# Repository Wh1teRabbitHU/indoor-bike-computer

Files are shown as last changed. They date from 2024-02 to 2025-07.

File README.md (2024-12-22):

# indoor-bike-computer

- [indoor-bike-computer](#indoor-bike-computer)
	- [Description](#description)
	- [Sensors](#sensors)
		- [Candelance sensor](#candelance-sensor)
		- [Difficulty sensor](#difficulty-sensor)
	- [Firmware](#firmware)
	- [Images](#images)
		- [Computer 3D render, Front](#computer-3d-render-front)
		- [Computer 3D render, Back](#computer-3d-render-back)

## Description

It's a custom computer for indoor bikes to measure cadence, speed and power, store sessions, visualise ongoing statistics and replace non chargeable solutions. This project is created for the [Joroto X2 Pro](https://jorotofitness.com/products/joroto-x2pro-bluetooth-stationary-exercise-bike) indoor bike, but can be used with any other, similarly operating bikes as well!

The sensors connect to the unit the following way:

There are 2 sensor headers on the computer, one for the Candelance sensor and the other to measure the manual difficulty adjustment knob.

## Sensors

### Candelance sensor

You need to connect the following 2 pins:

- Revolution signal: This signal sends a pulse whenever the bike's crank is aligned with the sensor. The signal is triggered once every revolution and the speed is calculated based on the time difference between two pulse. For precise distance measurement, you can change the default values of the bike in the settings.
- GND: This is the shared GND line

### Difficulty sensor

You need to connect the following 3 pins:

- +3V3: This powers the sensor on the bike
- Difficulty signal: This comes from the knob, and depending on the current difficulty level, it provides a voltage between GND and +3V3 volt. (it's not a linear value and there is a starting and ending voltage level) This can be calibrated in the settings on the computer for a precise measurement.
- GND: This is the shared GND line

## Firmware

I'm using [LVGL](https://lvgl.io/) an open source embedded graphics library, to handle the UI elements for the computer. The drivers for the various chips and the bike are custom made and can be located under the `Firmware/STM32F446/Core/Inc/Drivers` and `Firmware/STM32F446/Core/Src/Drivers` folders.

List of drivers:

- ER_TFT035: Display driver. [Details](https://www.buydisplay.com/serial-spi-3-5-inch-tft-lcd-module-in-320x480-optl-touchscreen-ili9488)
- MCP3421: ADC chip from MicroChip. [Details](https://www.microchip.com/en-us/product/mcp3421)
- SD card: SD card middleware on top of the FatFS implementation, to make handling file read and write simpler

## Images

### Computer 3D render, Front
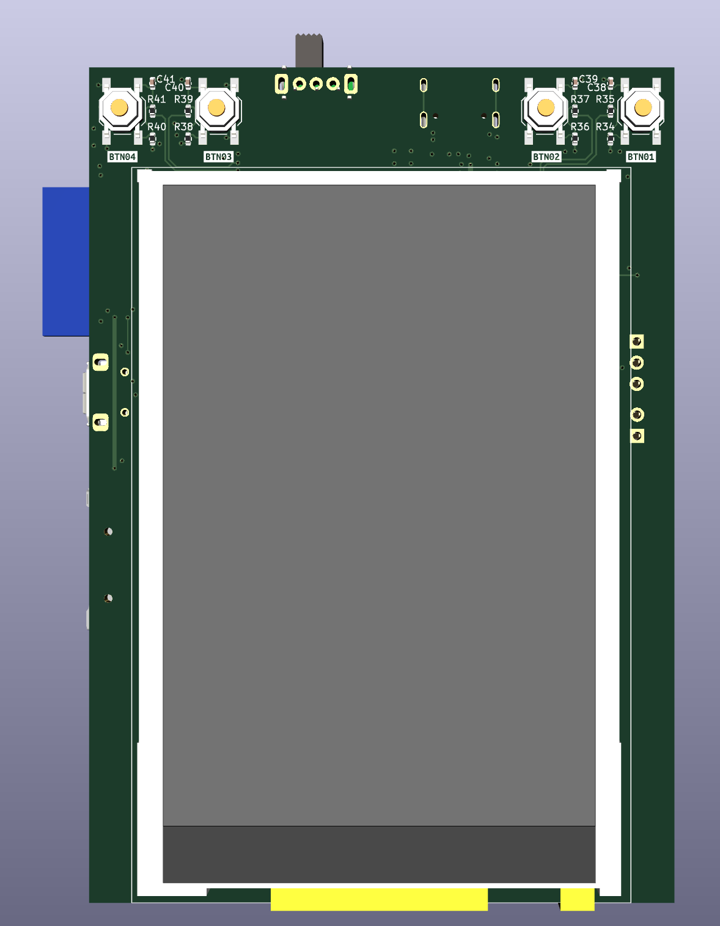
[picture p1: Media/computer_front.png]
Computer 3D - Front


### Computer 3D render, Back
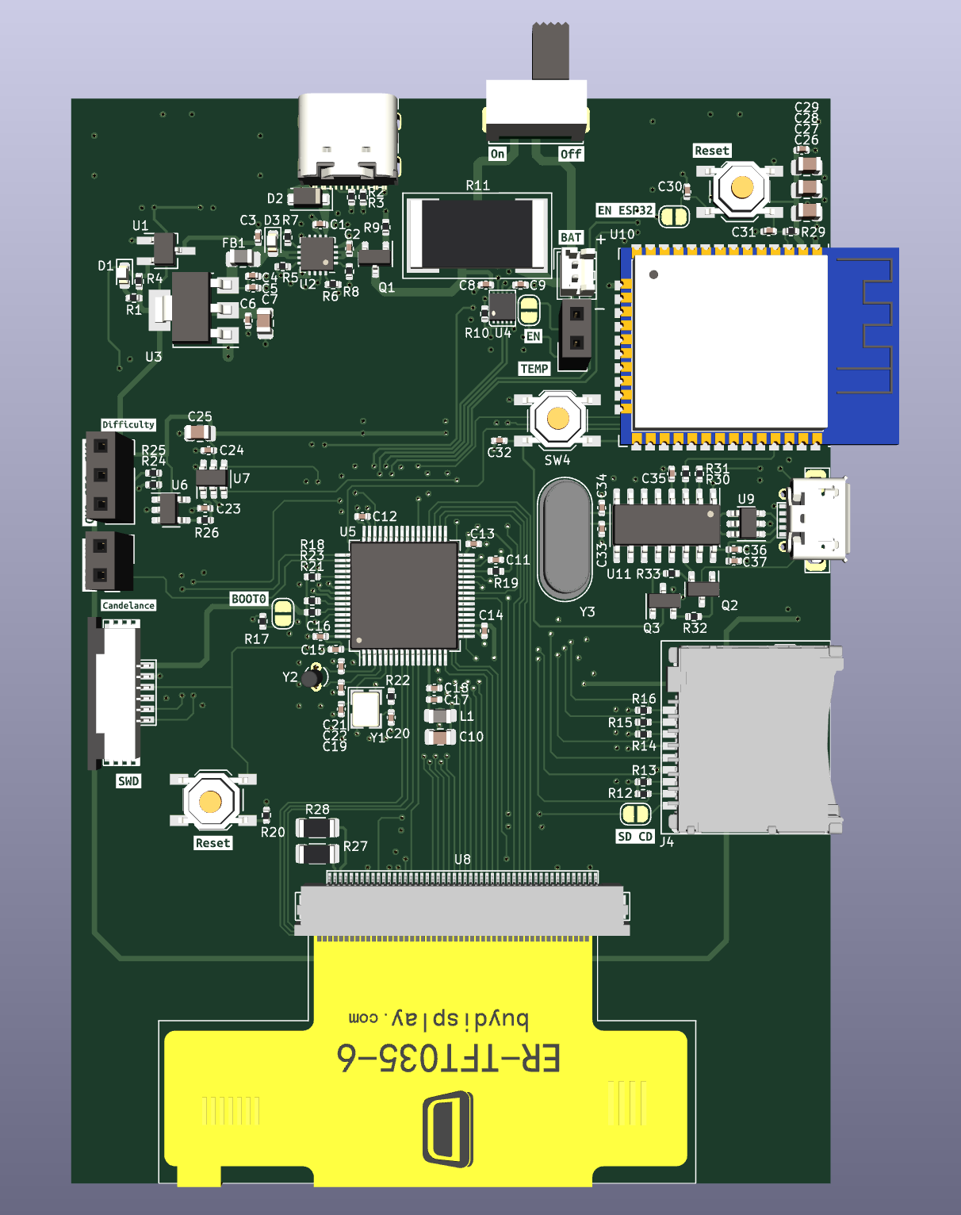
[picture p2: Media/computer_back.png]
Computer 3D - Back


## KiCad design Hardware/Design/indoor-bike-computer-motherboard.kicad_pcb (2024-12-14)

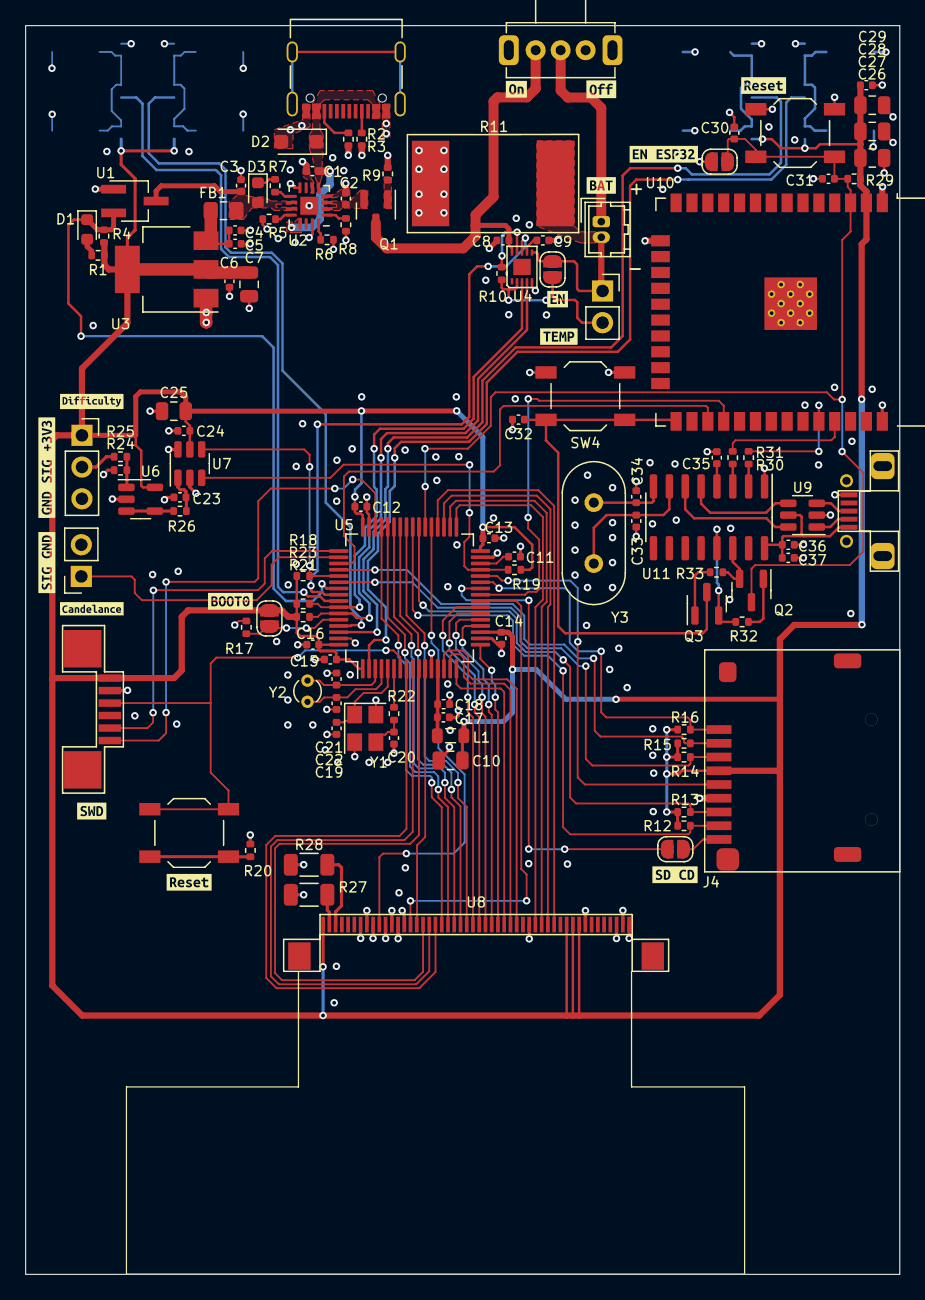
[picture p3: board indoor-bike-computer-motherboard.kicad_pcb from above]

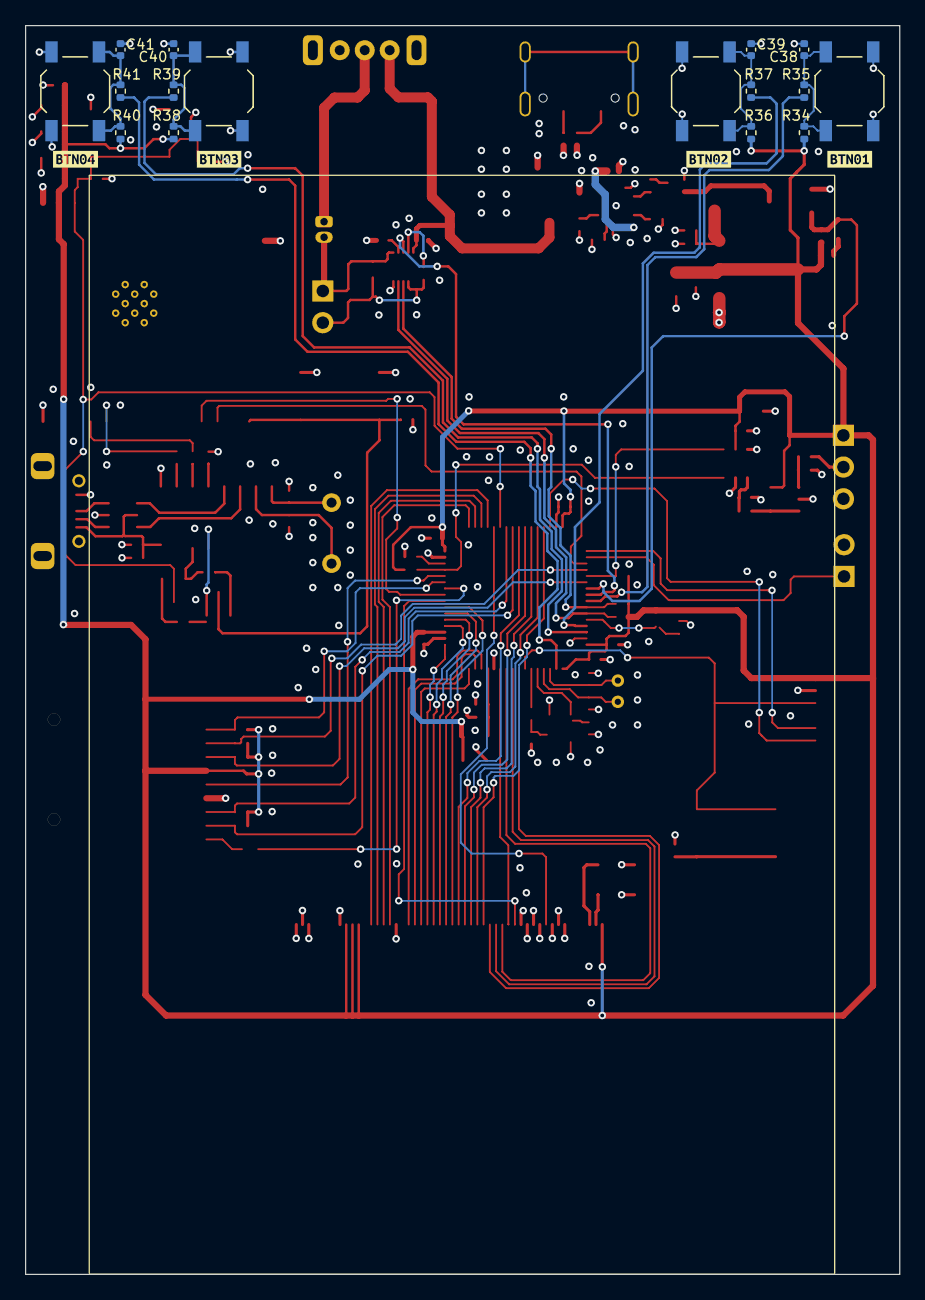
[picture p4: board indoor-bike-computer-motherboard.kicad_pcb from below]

Board: 4 copper layers, 70.0 x 100.0 mm, 143 parts (20 on the bottom side), 105 nets.

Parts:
C1, C9, C17, C23: 1uF; C_0402_1005Metric
C2, C3, C4, C11, C36: 4.7uF; C_0402_1005Metric
C5, C6, C8, C12, C13, C14, C15, C16, C18, C24, C29, C30, C31, C32, C35, C37, C38, C39, C40, C41: 0.1uF; C_0402_1005Metric
C7, C10, C25: 10uF; C_0805_2012Metric
C19, C20: 26pF; C_0402_1005Metric
C21, C22: 12pF; C_0402_1005Metric
C26, C27, C28: 22uF; C_0805_2012Metric
C33, C34: 15pF; C_0402_1005Metric
D1: Power Alert; LED_0603_1608Metric
D2: SMF6.0A; D_SOD-123F
D3: Charging; LED_0603_1608Metric
FB1: FerriteBead_Small; L_0805_2012Metric_Pad1.15x1.40mm_HandSolder
J1: USB_C_Receptacle_PowerOnly_6P; USB_C_Receptacle U262-161N-4BVC11
J2: Battery Terminal; Hirose_DF13-02P-1.25DSA_1x02_P1.25mm_Vertical
J3: THRM Socket; PinSocket_1x02_P2.54mm_Vertical
J4: Micro_SD_Card; MicroSD-TF-015
J5: SWD; AFA07-S06FCA-00
J6: Difficulty Header; PinSocket_1x03_P2.54mm_Vertical
J7: Candelance Header; PinSocket_1x02_P2.54mm_Vertical
J8: ESP32 Programmer; Micro_USB_B_Female
JP1: AIN_JMP; SolderJumper-2_P1.3mm_Open_RoundedPad1.0x1.5mm
JP2: SD_CD JP; SolderJumper-2_P1.3mm_Open_RoundedPad1.0x1.5mm
JP3: Jumper_2_Open; SolderJumper-2_P1.3mm_Open_RoundedPad1.0x1.5mm
JP4: EN_ESP32; SolderJumper-2_P1.3mm_Open_RoundedPad1.0x1.5mm
L1: 39nH; L_0805_2012Metric
Q1: AO3401A; SOT-23
Q2, Q3: BC849; SOT-23
R1: 1.5k; R_0402_1005Metric
R2, R3: 5.1kΩ; R_0402_1005Metric
R4: 100k; R_0402_1005Metric
R5: 1K1Ω; R_0402_1005Metric
R6: 590Ω; R_0402_1005Metric
R7, R35, R37, R39, R41: 1K; R_0402_1005Metric
R8, R9, R34, R36, R38, R40: 10K; R_0402_1005Metric
R10, R12, R13, R14, R15, R16, R17, R20, R24, R25, R29, R32, R33: 10k; R_0402_1005Metric
R11: 10mΩ; Resistor_SMD_4527
R18, R19, R21, R23: 2k2; R_0402_1005Metric
R22, R30, R31: 100; R_0402_1005Metric
R26: 220; R_0402_1005Metric
R27, R28: 10Ω; R_1206_3216Metric
SW1: Enable; Toggle-Switch-SK12D07VG4
SW2: Reset Button; SW_SPST_TL3342
SW3: Reset BTN; SW_SPST_TL3342
SW4: Flash BTN; SW_SPST_TL3342
SW5, SW6, SW7, SW8: Button_01; SW_SPST_TL3342
U1: APX803L05-36SA-7; SOT-23W_Handsoldering
U2: BQ24078RGTR; VQFN-16-1EP_3x3mm_P0.5mm_EP1.45x1.45mm
U3: LDL1117S33R; SOT-223-3_TabPin2
U4: MAX17055ETB+T; TDFN-EP-10-2.0x2.5
U5: STM32F446RETx; LQFP-64_10x10mm_P0.5mm
U6: LMV321; SOT-23-5
U7: MCP3421A0T-ECH; SOT-23-6
U8: ER-TFT035-6
U9: USBLC6-2SC6; SOT-23-6
U10: ESP32-WROOM-32
U11: CH340G; SOIC-16_3.9x9.9mm_P1.27mm
Y1: 8MHz; Crystal_SMD_Abracon_ABM8G-4Pin_3.2x2.5mm
Y2: 32768Hz; Crystal_Round_D1.5mm_Vertical
Y3: 12MHz; Crystal_HC49-4H_Vertical
kibuzzard-66A143C0: G***; kibuzzard-66A143C0
kibuzzard-66A143CA: G***; kibuzzard-66A143CA
kibuzzard-66A145A5: G***; kibuzzard-66A145A5
kibuzzard-66A145C4: G***; kibuzzard-66A145C4
kibuzzard-66A145EF: G***; kibuzzard-66A145EF
kibuzzard-66A146E2: G***; kibuzzard-66A146E2
kibuzzard-66A1432C: G***; kibuzzard-66A1432C
kibuzzard-66A1459C: G***; kibuzzard-66A1459C
kibuzzard-66A1487C: G***; kibuzzard-66A1487C
kibuzzard-66A1489C: G***; kibuzzard-66A1489C
kibuzzard-66A14353: G***; kibuzzard-66A14353
kibuzzard-66A14385: G***; kibuzzard-66A14385
kibuzzard-66A14397: G***; kibuzzard-66A14397
kibuzzard-66A14462: G***; kibuzzard-66A14462
kibuzzard-66A14469: G***; kibuzzard-66A14469
kibuzzard-66A14601: G***; kibuzzard-66A14601
kibuzzard-66A14776: G***; kibuzzard-66A14776
kibuzzard-66A14875: G***; kibuzzard-66A14875
kibuzzard-66A14886: G***; kibuzzard-66A14886

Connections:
+3.3VA: C17.1, C18.1, L1.1, U5.13 (VDDA)
/ESP32_MCU/+3V3: C6.1, C7.1, C10.1, C12.1, C13.1, C14.1, C15.1, C16.1, C24.2, C25.1, C26.1, C27.1, C28.1, C29.1, J4.4 (VDD), J5.1, J6.1, JP3.2 (B), L1.2, R1.1, R4.1, R12.2, R13.2, R14.2, R15.2, R16.2, R18.1, R19.1, R21.1, R23.1, R29.2, R34.1, R36.1, R38.1, R40.1, U3.2 (OUT), U5.1 (VBAT), U5.19 (VDD), U5.32 (VDD), U5.48 (VDD), U5.64 (VDD), U6.5 (V+), U7.5 (Vdd), U8.1 (LEDA), U8.40 (VDDI), U8.41 (VDDI), U8.42 (VCI), U10.2 (VDD)
/ESP32_MCU/ESP32_5V: C36.1, C37.1, J8.1 (VBUS), U9.5 (VBUS), U11.16 (VCC)
/ESP32_MCU/GND: C1.2, C2.2, C3.2, C4.2, C5.2, C6.2, C7.2, C8.2, C9.2, C10.2, C11.2, C12.2, C13.2, C14.2, C15.2, C16.2, C17.2, C18.2, C19.1, C20.2, C21.2, C22.2, C23.2, C24.1, C25.2, C26.2, C27.2, C28.2, C29.2, C30.2, C31.2, C32.2, C33.2, C34.2, C35.2, C36.2, C37.2, C38.2, C39.2, C40.2, C41.2, D2.2 (A2), J1.A1, J1.A12 (GND), J1.B1, J1.B12 (GND), J4.6 (VSS), J5.2, J6.3, J7.2, J8.5 (GND), JP4.1 (A), R2.2, R3.2, R5.1, R6.1, R8.2, R9.2, R11.2, R17.2, R20.2, R25.1, R27.2, R28.2, SW3.2, SW4.2, SW5.1, SW6.1, SW7.1, SW8.1, U1.1 (GND), U2.4 (!CE), U2.6 (EN1), U2.8 (VSS), U2.15 (SYSOFF), U2.17 (PAD), U3.1 (GND), U4.5 (CSN), U5.12 (VSSA), U5.18 (VSS), U5.31 (VSS), U5.47 (VSS), U5.63 (VSS), U6.2 (V-), U7.2 (Vss), U7.6 (Vin-), U8.7 (IM0), U8.8 (IM1), U8.9 (IM2), U8.11 (VSYNC), U8.12 (HSYNC), U8.13 (DOTCLK), U8.14 (DE), U8.34 (SDA), U8.43 (GND), U8.48 (GND), U8.49 (GND), U8.50 (GND), U9.2 (GND), U10.1 (GND), U10.15 (GND), U10.38 (GND), U10.39 (GND), U11.1 (GND), Y1.2, Y1.4
/ESP32_MCU/IO0: C32.1, Q3.3 (C), SW4.1, U10.25 (IO0)
/ESP32_MCU/RXD0: R30.1, U10.34 (RXD0/IO3)
/ESP32_MCU/TXD0: R31.1, U10.35 (TXD0/IO1)
/ESP32_MCU/USB_D+: U9.4 (I/O2), U11.5 (UD+)
/ESP32_MCU/USB_D-: U9.6 (I/O1), U11.6 (UD-)
/ESP32_MCU/USB_D_IN+: J8.3 (D+), U9.3 (I/O2)
/ESP32_MCU/USB_D_IN-: J8.2 (D-), U9.1 (I/O1)
/Power Input/BAT+: C2.1, Q1.2 (S), U2.2 (BAT), U2.3 (BAT)
/Power Input/BAT_IN+: C8.1, Q1.3 (D), SW1.3 (C), U4.10 (BATT)
/Power Input/BAT_IN-: J2.2, J3.1, JP1.1 (A), R11.1, U4.6 (CSP)
/Power Input/PWR_OUT: C3.1, D3.2 (A), FB1.1, U1.3 (VCC), U2.10 (OUT), U2.11 (OUT)
/Power Input/VBUS: C1.1, D2.1 (A1), J1.A4, J1.A9 (VBUS), J1.B4, J1.B9 (VBUS), U2.5 (EN2), U2.13 (IN)
ADC_SCL: R19.2, U5.29 (PB10), U7.3 (SCL)
ADC_SDA: R18.2, U5.53 (PC12), U7.4 (SDA)
BOOT0: JP3.1 (A), R17.1, U5.60 (BOOT0)
DIFFICULTY_SIGNAL: J6.2, R24.2
DISPLAY_CS: U5.36 (PB15), U8.38 (CSX)
DISPLAY_D00: U5.14 (PA0), U8.32 (DB00)
DISPLAY_D01: U5.15 (PA1), U8.31 (DB01)
DISPLAY_D02: U5.16 (PA2), U8.30 (DB02)
DISPLAY_D03: U5.17 (PA3), U8.29 (DB03)
DISPLAY_D04: U5.20 (PA4), U8.28 (DB04)
DISPLAY_D05: U5.21 (PA5), U8.27 (DB05)
DISPLAY_D06: U5.22 (PA6), U8.26 (DB06)
DISPLAY_D07: U5.23 (PA7), U8.25 (DB07)
DISPLAY_D08: U5.41 (PA8), U8.24 (DB08)
DISPLAY_D09: U5.42 (PA9), U8.23 (DB09)
DISPLAY_D10: U5.43 (PA10), U8.22 (DB10)
DISPLAY_D11: U5.44 (PA11), U8.21 (DB11)
DISPLAY_D12: U5.45 (PA12), U8.20 (DB12)
DISPLAY_D13: U5.8 (PC0), U8.19 (DB13)
DISPLAY_D14: U5.9 (PC1), U8.18 (DB14)
DISPLAY_D15: U5.10 (PC2), U8.17 (DB15)
DISPLAY_D16: U5.11 (PC3), U8.16 (DB16)
DISPLAY_D17: U5.24 (PC4), U8.15 (DB17)
DISPLAY_DC: U5.35 (PB14), U8.37 (D/CX)
DISPLAY_RD: U5.33 (PB12), U8.35 (RD)
DISPLAY_RESET: U5.37 (PC6), U8.10 (RESET)
DISPLAY_WR: U5.34 (PB13), U8.36 (WRX/SCL)
NRST: J5.3, SW2.1, U5.7 (NRST)
unnamed: C20.1, R22.1, Y1.3
unnamed: C38.1, R34.2, R35.1, SW5.2
unnamed: C39.1, R36.2, R37.1, SW6.2
unnamed: C40.1, R38.2, R39.1, SW7.2
unnamed: C41.1, R40.2, R41.1, SW8.2
unnamed: D1.2 (A), R1.2
unnamed: D3.1 (K), R7.1
unnamed: J1.A5 (CC1), R3.1
unnamed: J1.B5 (CC2), R2.1
unnamed: J2.1, SW1.2 (B)
unnamed: J3.2, JP1.2 (B), R10.1, U4.2 (AIN)
unnamed: J4.9 (SHIELD), JP2.2 (B)
unnamed: Q1.1 (G), R9.1
unnamed: Q2.1 (B), R32.1
unnamed: Q2.2 (E), R33.2, U11.14 (~RTS)
unnamed: Q3.1 (B), R33.1
unnamed: Q3.2 (E), R32.2, U11.13 (~DTR)
unnamed: R20.1, SW2.2
unnamed: R27.1, U8.2 (LEDK)
unnamed: R28.1, U8.3 (LEDK)
unnamed: R7.2, U2.9 (!CHG)
unnamed: R5.2, U2.12 (ILIM)
unnamed: R6.2, U2.16 (ISET)
unnamed: R8.1, U2.1 (TS)
unnamed: C4.1, C5.1, FB1.2, U3.3 (VIN)
unnamed: C9.1, U4.7 (REG)
unnamed: R10.2, U4.9 (THRM)
unnamed: C11.1, U5.30 (VCAP_1)
unnamed: R24.1, R25.2, U6.1 (+)
unnamed: R26.1, U6.3 (-), U6.4
unnamed: C23.1, R26.2, U7.1 (Vin+)
unnamed: R31.2, U11.3 (RXD)
unnamed: R30.2, U11.2 (TXD)
unnamed: C35.1, U11.4 (V3)
unnamed: C33.1, U11.7 (XI), Y3.1
unnamed: C34.1, U11.8 (XO), Y3.2
OSC_IN: C19.2, U5.5 (PH0), Y1.1
OSC_OUT: R22.2, U5.6 (PH1)
PA13: J5.6, U5.46 (PA13)
PA14: J5.5, U5.49 (PA14)
PA15: J7.1, U5.50 (PA15)
PB0: JP2.1 (A), U5.26 (PB0)
PB1: J4.1 (DAT2), R16.1, U5.27 (PB1)
PB2: J4.5 (CLK), U5.28 (PB2)
PB3: D1.1 (K), R4.2, U1.2 (!RESET), U5.55 (PB3)
PB4: U4.8 (ALERT), U5.56 (PB4)
PB5: R35.2, U5.57 (PB5)
PB6: R23.2, U4.3 (SCL), U5.58 (PB6)
PB7: R21.2, U4.4 (SDA), U5.59 (PB7)
PB8: R37.2, U5.61 (PB8)
PB9: R39.2, U5.62 (PB9)
PC5: U5.25 (PC5), U10.28 (IO17)
PC7: C30.1, C31.1, JP4.2 (B), Q2.3 (C), R29.1, SW3.1, U5.38 (PC7), U10.3 (EN)
PC8: J4.7 (DAT0), R13.1, U5.39 (PC8)
PC9: J4.8 (DAT1), R12.1, U5.40 (PC9)
PC10: U5.51 (PC10), U10.27 (IO16)
PC11: J4.2 (DAT3/CD), R15.1, U5.52 (PC11)
PC13: R41.2, U5.2 (PC13)
PC14: C21.1, U5.3 (PC14), Y2.1
PC15: C22.1, U5.4 (PC15), Y2.2
PD2: J4.3 (CMD), R14.1, U5.54 (PD2)

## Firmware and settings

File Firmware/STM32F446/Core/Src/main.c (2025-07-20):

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
/* Includes ------------------------------------------------------------------*/
#include "main.h"
#include "fatfs.h"

/* USER CODE BEGIN Includes */
#include "bike.h"
#include "config.h"
#include "data.h"
#include "er_tft035.h"
#include "esp32_uart.h"
#include "gui.h"
#include "main_screen.h"
#include "max17055.h"
#include "mcp3421.h"
#include "stdio.h"
/* USER CODE END Includes */

I2C_HandleTypeDef hi2c1;
I2C_HandleTypeDef hi2c2;

RTC_HandleTypeDef hrtc;

SD_HandleTypeDef hsd;

TIM_HandleTypeDef htim6;
TIM_HandleTypeDef htim7;
TIM_HandleTypeDef htim14;

UART_HandleTypeDef huart3;
DMA_HandleTypeDef hdma_usart3_rx;
DMA_HandleTypeDef hdma_usart3_tx;

void SystemClock_Config(void);
static void MX_GPIO_Init(void);
static void MX_DMA_Init(void);
static void MX_I2C1_Init(void);
static void MX_I2C2_Init(void);
static void MX_SDIO_SD_Init(void);
static void MX_USART3_UART_Init(void);
static void MX_RTC_Init(void);
static void MX_TIM14_Init(void);
static void MX_TIM6_Init(void);
static void MX_TIM7_Init(void);
/* USER CODE BEGIN 0 */

void SDCard_handleError(FRESULT result, char * message) {
    MainScreen_showAlert(ALERT_MODAL_VARIANT_ERROR, 1, "SD card error", message);
}

/* USER CODE END 0 */

/**
 * @brief  The application entry point.
 * @retval int
 */
int main(void) {
    /* MCU Configuration--------------------------------------------------------*/

    /* Reset of all peripherals, Initializes the Flash interface and the Systick. */
    HAL_Init();

    /* Configure the system clock */
    SystemClock_Config();

    /* Initialize all configured peripherals */
    MX_GPIO_Init();
    MX_DMA_Init();
    MX_I2C1_Init();
    MX_I2C2_Init();
    MX_SDIO_SD_Init();
    MX_USART3_UART_Init();
    MX_RTC_Init();
    MX_TIM14_Init();
    MX_FATFS_Init();
    MX_TIM6_Init();
    MX_TIM7_Init();
    /* USER CODE BEGIN 2 */

    Bike_init(&htim6);
    GUI_init();

    uint8_t sdCardOk = Data_initStorage();

    if (sdCardOk) {
        Data_loadStatistics();
        Config_load();
    } else {
        MainScreen_showAlert(ALERT_MODAL_VARIANT_ERROR, 0, "SD card error", "Unable to initialize the computer, the SD card is missing or not readable!");
    }

    HAL_StatusTypeDef adcInitResult = MCP3421_init(&hi2c2);

    if (adcInitResult == HAL_OK) {
        HAL_TIM_Base_Start_IT(&htim14); // Start timer
        HAL_TIM_Base_Start_IT(&htim7);
    } else if (sdCardOk) {
        MainScreen_showAlert(ALERT_MODAL_VARIANT_ERROR, 0, "Sensor error", "Unable to initialize the computer, one of the sensors is not responding!");
    }

    // MAX17055_init(&hi2c1);

    ESP32_initCommunication(&huart3);

    /* USER CODE END 2 */

    /* Infinite loop */
    /* USER CODE BEGIN WHILE */
    // MAX17055_measurements measurements;

    while (1) {
        /* USER CODE END WHILE */

        /* USER CODE BEGIN 3 */
        uint32_t waitTime = GUI_tick();

        HAL_Delay(waitTime);

        // MAX17055_readMeasurements(&measurements);
        // sprintf(stringBuffer, "Measurements:\n%lu, %lu,\n %lu, %lu", measurements.instantVoltage, measurements.instantCurrent, measurements.instantCapacity, measurements.temperature);
        // MainScreen_showAlert(ALERT_MODAL_VARIANT_INFO, 0, "Measurements", stringBuffer);
    }
    /* USER CODE END 3 */
}

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
/* USER CODE BEGIN 4 */

ESP32_UART_Packet packet = {0};

void HAL_UART_RxCpltCallback(UART_HandleTypeDef * huart) {
    ESP32_receiveData(&packet);

    MainScreen_showAlert(ALERT_MODAL_VARIANT_INFO, 0, "Received Data", (char *)packet.data);
}

/* USER CODE END 4 */
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


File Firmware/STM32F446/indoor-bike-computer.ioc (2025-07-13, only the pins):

Mcu.UserName=STM32F446RETx
PA0-WKUP.GPIO_Label=DISPLAY_D00
PA0-WKUP.Signal=GPIO_Output
PA1.GPIO_Label=DISPLAY_D01
PA1.Signal=GPIO_Output
PA10.GPIO_Label=DISPLAY_D10
PA10.Signal=GPIO_Output
PA11.GPIO_Label=DISPLAY_D11
PA11.Signal=GPIO_Output
PA12.GPIO_Label=DISPLAY_D12
PA12.Signal=GPIO_Output
PA13.Signal=SYS_JTMS-SWDIO
PA14.Signal=SYS_JTCK-SWCLK
PA15.GPIO_Label=REVOLUTION_SIGNAL
PA15.Signal=GPXTI15
PA2.GPIO_Label=DISPLAY_D02
PA2.Signal=GPIO_Output
PA3.GPIO_Label=DISPLAY_D03
PA3.Signal=GPIO_Output
PA4.GPIO_Label=DISPLAY_D04
PA4.Signal=GPIO_Output
PA5.GPIO_Label=DISPLAY_D05
PA5.Signal=GPIO_Output
PA6.GPIO_Label=DISPLAY_D06
PA6.Signal=GPIO_Output
PA7.GPIO_Label=DISPLAY_D07
PA7.Signal=GPIO_Output
PA8.GPIO_Label=DISPLAY_D08
PA8.Signal=GPIO_Output
PA9.GPIO_Label=DISPLAY_D09
PA9.Signal=GPIO_Output
PB0.GPIO_Label=SDIO_CD
PB0.Signal=GPIO_Input
PB10.Signal=I2C2_SCL
PB12.GPIO_Label=DISPLAY_RD
PB12.Signal=GPIO_Output
PB13.GPIO_Label=DISPLAY_WR
PB13.Signal=GPIO_Output
PB14.GPIO_Label=DISPLAY_DC
PB14.Signal=GPIO_Output
PB15.GPIO_Label=DISPLAY_CS
PB15.Signal=GPIO_Output
PB2.Signal=SDIO_CK
PB3.GPIO_Label=POWER_ALERT
PB3.Signal=GPIO_Input
PB4.GPIO_Label=GAUGE_ALERT
PB4.Signal=GPIO_Output
PB5.GPIO_Label=USER_BTN_1
PB5.Signal=GPXTI5
PB6.Signal=I2C1_SCL
PB7.Signal=I2C1_SDA
PB8.GPIO_Label=USER_BTN_2
PB8.Signal=GPXTI8
PB9.GPIO_Label=USER_BTN_3
PB9.Signal=GPXTI9
PC0.GPIO_Label=DISPLAY_D13
PC0.Signal=GPIO_Output
PC1.GPIO_Label=DISPLAY_D14
PC1.Signal=GPIO_Output
PC10.Signal=USART3_TX
PC12.Signal=I2C2_SDA
PC13.GPIO_Label=USER_BTN_4
PC13.Signal=GPXTI13
PC14-OSC32_IN.Signal=RCC_OSC32_IN
PC15-OSC32_OUT.Signal=RCC_OSC32_OUT
PC2.GPIO_Label=DISPLAY_D15
PC2.Signal=GPIO_Output
PC3.GPIO_Label=DISPLAY_D16
PC3.Signal=GPIO_Output
PC4.GPIO_Label=DISPLAY_D17
PC4.Signal=GPIO_Output
PC5.Signal=USART3_RX
PC6.GPIO_Label=DISPLAY_RESET
PC6.Signal=GPIO_Output
PC7.GPIO_Label=ESP32_EN
PC7.Signal=GPIO_Output
PC8.Signal=SDIO_D0
PD2.Signal=SDIO_CMD
PH0-OSC_IN.Signal=RCC_OSC_IN
PH1-OSC_OUT.Signal=RCC_OSC_OUT

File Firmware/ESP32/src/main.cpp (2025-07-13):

#include <Arduino.h>
#include <string.h>

void setup() {
    Serial.begin(115200);
    Serial2.begin(115200);

    delay(10);

    // We start by connecting to a WiFi network

    Serial.println();
    Serial.println();
    Serial.print("ESP32 is ready");
    Serial.println();
    Serial.println();
}

char logBuffer[128] = {'\0'};
char rxBuffer[64] = {'\0'};
char txBuffer[64] = {'\0'};
char dataBuffer[64] = {'\0'};
uint32_t counter = 0;
uint8_t bufferPointer = 0;

static const uint32_t crc32Table[256] = {
    0x00000000L, 0xF26B8303L, 0xE13B70F7L, 0x1350F3F4L, 0xC79A971FL, 0x35F1141CL, 0x26A1E7E8L, 0xD4CA64EBL, 0x8AD958CFL,
    0x78B2DBCCL, 0x6BE22838L, 0x9989AB3BL, 0x4D43CFD0L, 0xBF284CD3L, 0xAC78BF27L, 0x5E133C24L, 0x105EC76FL, 0xE235446CL,
    0xF165B798L, 0x030E349BL, 0xD7C45070L, 0x25AFD373L, 0x36FF2087L, 0xC494A384L, 0x9A879FA0L, 0x68EC1CA3L, 0x7BBCEF57L,
    0x89D76C54L, 0x5D1D08BFL, 0xAF768BBCL, 0xBC267848L, 0x4E4DFB4BL, 0x20BD8EDEL, 0xD2D60DDDL, 0xC186FE29L, 0x33ED7D2AL,
    0xE72719C1L, 0x154C9AC2L, 0x061C6936L, 0xF477EA35L, 0xAA64D611L, 0x580F5512L, 0x4B5FA6E6L, 0xB93425E5L, 0x6DFE410EL,
    0x9F95C20DL, 0x8CC531F9L, 0x7EAEB2FAL, 0x30E349B1L, 0xC288CAB2L, 0xD1D83946L, 0x23B3BA45L, 0xF779DEAEL, 0x05125DADL,
    0x1642AE59L, 0xE4292D5AL, 0xBA3A117EL, 0x4851927DL, 0x5B016189L, 0xA96AE28AL, 0x7DA08661L, 0x8FCB0562L, 0x9C9BF696L,
    0x6EF07595L, 0x417B1DBCL, 0xB3109EBFL, 0xA0406D4BL, 0x522BEE48L, 0x86E18AA3L, 0x748A09A0L, 0x67DAFA54L, 0x95B17957L,
    0xCBA24573L, 0x39C9C670L, 0x2A993584L, 0xD8F2B687L, 0x0C38D26CL, 0xFE53516FL, 0xED03A29BL, 0x1F682198L, 0x5125DAD3L,
    0xA34E59D0L, 0xB01EAA24L, 0x42752927L, 0x96BF4DCCL, 0x64D4CECFL, 0x77843D3BL, 0x85EFBE38L, 0xDBFC821CL, 0x2997011FL,
    0x3AC7F2EBL, 0xC8AC71E8L, 0x1C661503L, 0xEE0D9600L, 0xFD5D65F4L, 0x0F36E6F7L, 0x61C69362L, 0x93AD1061L, 0x80FDE395L,
    0x72966096L, 0xA65C047DL, 0x5437877EL, 0x4767748AL, 0xB50CF789L, 0xEB1FCBADL, 0x197448AEL, 0x0A24BB5AL, 0xF84F3859L,
    0x2C855CB2L, 0xDEEEDFB1L, 0xCDBE2C45L, 0x3FD5AF46L, 0x7198540DL, 0x83F3D70EL, 0x90A324FAL, 0x62C8A7F9L, 0xB602C312L,
    0x44694011L, 0x5739B3E5L, 0xA55230E6L, 0xFB410CC2L, 0x092A8FC1L, 0x1A7A7C35L, 0xE811FF36L, 0x3CDB9BDDL, 0xCEB018DEL,
    0xDDE0EB2AL, 0x2F8B6829L, 0x82F63B78L, 0x709DB87BL, 0x63CD4B8FL, 0x91A6C88CL, 0x456CAC67L, 0xB7072F64L, 0xA457DC90L,
    0x563C5F93L, 0x082F63B7L, 0xFA44E0B4L, 0xE9141340L, 0x1B7F9043L, 0xCFB5F4A8L, 0x3DDE77ABL, 0x2E8E845FL, 0xDCE5075CL,
    0x92A8FC17L, 0x60C37F14L, 0x73938CE0L, 0x81F80FE3L, 0x55326B08L, 0xA759E80BL, 0xB4091BFFL, 0x466298FCL, 0x1871A4D8L,
    0xEA1A27DBL, 0xF94AD42FL, 0x0B21572CL, 0xDFEB33C7L, 0x2D80B0C4L, 0x3ED04330L, 0xCCBBC033L, 0xA24BB5A6L, 0x502036A5L,
    0x4370C551L, 0xB11B4652L, 0x65D122B9L, 0x97BAA1BAL, 0x84EA524EL, 0x7681D14DL, 0x2892ED69L, 0xDAF96E6AL, 0xC9A99D9EL,
    0x3BC21E9DL, 0xEF087A76L, 0x1D63F975L, 0x0E330A81L, 0xFC588982L, 0xB21572C9L, 0x407EF1CAL, 0x532E023EL, 0xA145813DL,
    0x758FE5D6L, 0x87E466D5L, 0x94B49521L, 0x66DF1622L, 0x38CC2A06L, 0xCAA7A905L, 0xD9F75AF1L, 0x2B9CD9F2L, 0xFF56BD19L,
    0x0D3D3E1AL, 0x1E6DCDEEL, 0xEC064EEDL, 0xC38D26C4L, 0x31E6A5C7L, 0x22B65633L, 0xD0DDD530L, 0x0417B1DBL, 0xF67C32D8L,
    0xE52CC12CL, 0x1747422FL, 0x49547E0BL, 0xBB3FFD08L, 0xA86F0EFCL, 0x5A048DFFL, 0x8ECEE914L, 0x7CA56A17L, 0x6FF599E3L,
    0x9D9E1AE0L, 0xD3D3E1ABL, 0x21B862A8L, 0x32E8915CL, 0xC083125FL, 0x144976B4L, 0xE622F5B7L, 0xF5720643L, 0x07198540L,
    0x590AB964L, 0xAB613A67L, 0xB831C993L, 0x4A5A4A90L, 0x9E902E7BL, 0x6CFBAD78L, 0x7FAB5E8CL, 0x8DC0DD8FL, 0xE330A81AL,
    0x115B2B19L, 0x020BD8EDL, 0xF0605BEEL, 0x24AA3F05L, 0xD6C1BC06L, 0xC5914FF2L, 0x37FACCF1L, 0x69E9F0D5L, 0x9B8273D6L,
    0x88D28022L, 0x7AB90321L, 0xAE7367CAL, 0x5C18E4C9L, 0x4F48173DL, 0xBD23943EL, 0xF36E6F75L, 0x0105EC76L, 0x12551F82L,
    0xE03E9C81L, 0x34F4F86AL, 0xC69F7B69L, 0xD5CF889DL, 0x27A40B9EL, 0x79B737BAL, 0x8BDCB4B9L, 0x988C474DL, 0x6AE7C44EL,
    0xBE2DA0A5L, 0x4C4623A6L, 0x5F16D052L, 0xAD7D5351L};

static inline uint32_t calculateCRC(uint8_t* data, uint32_t dataLength) {
    uint32_t crc = 0xFFFFFFFF;
    const uint8_t* p = data;

    while (dataLength--) {
        crc = crc32Table[(crc ^ *p++) & 0xff] ^ (crc >> 8);
    }

    return crc;
}

static inline uint32_t read32BitData(char* buffer, uint8_t start) {
    uint32_t data = 0;

    data |= buffer[start] << 24;
    data |= buffer[start + 1] << 16;
    data |= buffer[start + 2] << 8;
    data |= buffer[start + 3];

    return data;
}

void loop() {
    while (Serial2.available()) {
        rxBuffer[bufferPointer++] = (char)Serial2.read();
    }

    if (bufferPointer > 0) {
        uint32_t packetID = read32BitData(rxBuffer, 0);
        uint8_t command = rxBuffer[4];
        uint8_t dataLength = rxBuffer[5];
        memcpy(dataBuffer, rxBuffer + 6, dataLength);
        uint32_t crcSent = read32BitData(rxBuffer, dataLength + 6);
        uint32_t crcCalculated = calculateCRC((uint8_t*)rxBuffer, dataLength + 6);
        sprintf(logBuffer, "[%09lu] <%u> (%08X <=> %08X) %s", packetID, command, crcSent, crcCalculated, dataBuffer);
        Serial.println(logBuffer);
        bufferPointer = 0;

        if (crcSent == crcCalculated) {
            sprintf(txBuffer, "[%09lu] %s\n\0", packetID, "Received!");
        } else {
            sprintf(txBuffer, "%s\0", "Failed!");
        }

        Serial2.write(txBuffer, 64);
        Serial2.flush();
    }
}

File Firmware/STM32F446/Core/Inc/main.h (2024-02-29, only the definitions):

#define USER_BTN_4_Pin GPIO_PIN_13
#define USER_BTN_4_GPIO_Port GPIOC
#define USER_BTN_4_EXTI_IRQn EXTI15_10_IRQn
#define DISPLAY_D13_Pin GPIO_PIN_0
#define DISPLAY_D13_GPIO_Port GPIOC
#define DISPLAY_D14_Pin GPIO_PIN_1
#define DISPLAY_D14_GPIO_Port GPIOC
#define DISPLAY_D15_Pin GPIO_PIN_2
#define DISPLAY_D15_GPIO_Port GPIOC
#define DISPLAY_D16_Pin GPIO_PIN_3
#define DISPLAY_D16_GPIO_Port GPIOC
#define DISPLAY_D00_Pin GPIO_PIN_0
#define DISPLAY_D00_GPIO_Port GPIOA
#define DISPLAY_D01_Pin GPIO_PIN_1
#define DISPLAY_D01_GPIO_Port GPIOA
#define DISPLAY_D02_Pin GPIO_PIN_2
#define DISPLAY_D02_GPIO_Port GPIOA
#define DISPLAY_D03_Pin GPIO_PIN_3
#define DISPLAY_D03_GPIO_Port GPIOA
#define DISPLAY_D04_Pin GPIO_PIN_4
#define DISPLAY_D04_GPIO_Port GPIOA
#define DISPLAY_D05_Pin GPIO_PIN_5
#define DISPLAY_D05_GPIO_Port GPIOA
#define DISPLAY_D06_Pin GPIO_PIN_6
#define DISPLAY_D06_GPIO_Port GPIOA
#define DISPLAY_D07_Pin GPIO_PIN_7
#define DISPLAY_D07_GPIO_Port GPIOA
#define DISPLAY_D17_Pin GPIO_PIN_4
#define DISPLAY_D17_GPIO_Port GPIOC
#define SDIO_CD_Pin GPIO_PIN_0
#define SDIO_CD_GPIO_Port GPIOB
#define DISPLAY_RD_Pin GPIO_PIN_12
#define DISPLAY_RD_GPIO_Port GPIOB
#define DISPLAY_WR_Pin GPIO_PIN_13
#define DISPLAY_WR_GPIO_Port GPIOB
#define DISPLAY_DC_Pin GPIO_PIN_14
#define DISPLAY_DC_GPIO_Port GPIOB
#define DISPLAY_CS_Pin GPIO_PIN_15
#define DISPLAY_CS_GPIO_Port GPIOB
#define DISPLAY_RESET_Pin GPIO_PIN_6
#define DISPLAY_RESET_GPIO_Port GPIOC
#define ESP32_EN_Pin GPIO_PIN_7
#define ESP32_EN_GPIO_Port GPIOC
#define DISPLAY_D08_Pin GPIO_PIN_8
#define DISPLAY_D08_GPIO_Port GPIOA
#define DISPLAY_D09_Pin GPIO_PIN_9
#define DISPLAY_D09_GPIO_Port GPIOA
#define DISPLAY_D10_Pin GPIO_PIN_10
#define DISPLAY_D10_GPIO_Port GPIOA
#define DISPLAY_D11_Pin GPIO_PIN_11
#define DISPLAY_D11_GPIO_Port GPIOA
#define DISPLAY_D12_Pin GPIO_PIN_12
#define DISPLAY_D12_GPIO_Port GPIOA
#define REVOLUTION_SIGNAL_Pin GPIO_PIN_15
#define REVOLUTION_SIGNAL_GPIO_Port GPIOA
#define REVOLUTION_SIGNAL_EXTI_IRQn EXTI15_10_IRQn
#define POWER_ALERT_Pin GPIO_PIN_3
#define POWER_ALERT_GPIO_Port GPIOB
#define GAUGE_ALERT_Pin GPIO_PIN_4
#define GAUGE_ALERT_GPIO_Port GPIOB
#define USER_BTN_1_Pin GPIO_PIN_5
#define USER_BTN_1_GPIO_Port GPIOB
#define USER_BTN_1_EXTI_IRQn EXTI9_5_IRQn
#define USER_BTN_2_Pin GPIO_PIN_8
#define USER_BTN_2_GPIO_Port GPIOB
#define USER_BTN_2_EXTI_IRQn EXTI9_5_IRQn
#define USER_BTN_3_Pin GPIO_PIN_9
#define USER_BTN_3_GPIO_Port GPIOB
#define USER_BTN_3_EXTI_IRQn EXTI9_5_IRQn

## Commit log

2024-02-26 Init STM32 project
2024-02-26 basic 18 bit display driver
2024-02-26 advanced 18 bit display driver
2024-02-28 Reading difficulty sensor
2024-02-28 Moving the STM32 firmware under a subfolder
2024-02-29 Add ESP32 base project
2024-02-29 Enable interrupts
2024-02-29 Added general timer (to read difficulty value later)
2024-03-03 Making the GUI library thread safe
2024-03-06 Add timer element
2024-03-06 Working timer
2024-03-25 Add tab view components and handle button press
2024-03-31 Speed up the display driver
2024-08-11 Refactoring the SD card driver, adding new functions and preparing the data interface
2024-10-06 Linking the history tab functions to the flow handlers
2024-10-26 Fix load and scrolling
    [data.h]
2024-11-01 Adding a summary box on the history tab and change format + some smaller fixes
    [data.h]
2024-11-30 Making the run details buttons work and fixing the indexing issue on the history tab
2024-12-14 Adding the hardware design to the repository
    [button.kicad_sch, esp32-mcu.kicad_sch, indoor-bike-computer-motherboard.kicad_pcb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]
2024-12-25 Fixing some configuration issues
    [indoor-bike-computer.ioc, main.c]
2025-01-04 Adding max17055 driver, part 1
2025-01-04 Fixing the revolution measurement issues while the session is running
    [indoor-bike-computer.ioc]
2025-01-04 Using timers instead of the system clock to measure elapsed time between crank revolutions
2025-01-04 Fixing the MCP3421 measurements
    [mcp3421.c, mcp3421.h]
2025-01-12 Basic ESP32 config to receive UART data from the STM32
2025-02-16 Adding config handler and small refactor of the MCP3421 driver
2025-02-16 Fixing the SDCard_readLine and SDCard_readLines methods Adding missing config attribute parser implementation
    [config.h]
2025-02-16 Allow SD card error handling in debug mode; reformat header
    [main.c]
2025-06-09 Sending data to the ESP32, with checksum
2025-07-13 Setting up two way DMA UART communication
2025-07-20 Refactor the UART handling in both the ESP and STM library

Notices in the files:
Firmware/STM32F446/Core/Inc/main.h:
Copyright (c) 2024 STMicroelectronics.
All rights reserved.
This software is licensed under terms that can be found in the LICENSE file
